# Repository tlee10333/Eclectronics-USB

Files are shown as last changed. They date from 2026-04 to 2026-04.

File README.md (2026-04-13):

# Eclectronics Spring 2026 Final Project - Wireless USB Communication Board 
## By: Allan Huang, Trinity Lee, Venkadesh Eswaranandam

This repository contains documentation for a wireless USB communication board. 
TBD

# Documentation
Below are links to documentation provided by the official manufacturers and were used as reference for this project in schematic design and layout. 

## Nordic Semiconductor nRF5340 
[General Documentation Website](https://docs.nordicsemi.com/category/nrf5340-category)

[Download link to Product Specification PDF/Datasheet v1.6](https://docs-be.nordicsemi.com/bundle/ps_nrf5340/page/nRF5340_PS_v1.6.pdf?_LANG=enus) 

## Nordic Semiconductor nRF7002 
[General Documentation Website](https://docs.nordicsemi.com/category/nrf7002-category)

[Download link to Product Specification PDF/Datasheet v1.2](https://docs-be.nordicsemi.com/bundle/ps_nrf7002/attach/nRF7002_PS_v1.2.pdf?_LANG=enus)

## TS3USB30E Mux

[General Documentation Website](https://www.ti.com/product/TS3USB30E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)

[Link to Product Specification PDF/Datasheet](https://www.ti.com/lit/ds/symlink/ts3usb30e.pdf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)

## TBD
[General Documentation Website]()

[Download link to Product Specification PDF/Datasheet]()

# References
Below are links that were used for references (cthis section can be deleted if we want to)

[nRF7002 DK datasheet](https://docs-be.nordicsemi.com/bundle/ug_nrf7002_dk/attach/nRF7002_DK_User_Guide_v1.0.0.pdf?_LANG=enus)

[nRF5340 DK datasheet](https://docs-be.nordicsemi.com/bundle/ug_nrf5340_dk/attach/nRF5340_DK_User_Guide_v2.0.2.pdf?_LANG=enus)

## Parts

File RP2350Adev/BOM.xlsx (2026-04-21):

Id | Designator | Footprint | Quantity | Designation | Supplier and ref
1 | R405,R102,R101,R404 | R_0402_1005Metric | 4 | 27Ω
2 | R702,R701,R703,R704 | C_0402_1005Metric | 4 | 10K
3 | C407,C402,C417,C409,C410,C412,C408,C415,C411,C406 | R_0402_1005Metric | 10 | 0.1µF
4 | C201,C202 | C_0603_1608Metric | 2 | 4.7µF
5 | U201 | Nordic_AQFN-94-1EP_7x7mm_P0.4mm | 1 | nRF5340-QKxx
6 | D402,D201 | LED_0805_2012Metric | 2 | LED
7 | R201 | R_0402_1005Metric | 1 | 2.2 Ω
8 | U401 | SOT-223-3_TabPin2 | 1 | LD1117S33TR_SOT223
9 | C302,C303 | C_0603_1608Metric | 2 | 100nF
10 | C212,C214,C204,C215,C210,C213,C216,C211,C217 | C_0402_1005Metric | 9 | 100nF
11 | C308 | C_0603_1608Metric | 1 | 0.22uF
12 | C208,C203,C206,C207,C209 | C_0402_1005Metric | 5 | 1.0µF
13 | R705,R706 | C_0402_1005Metric | 2 | 5.1K
14 | D401 | LED_0805_2012Metric | 1 | PWR
15 | A301 | XCVR_NN03-320 | 1 | NN03-320
16 | J204 | PinHeader_1x03_P2.54mm_Vertical | 1 | UART Pins
17 | R406 | R_0402_1005Metric | 1 | 33Ω
18 | R401,R402,R408 | R_0402_1005Metric | 3 | 5.1K
19 | R410,R409,R202,R403,R407 | R_0402_1005Metric | 5 | 1K
20 | C314,C301 | C_0603_1608Metric | 2 | 0.47uF
21 | C306 | C_0805_2012Metric | 1 | 2.2uF
22 | R305,R302,R301,R303,R304 | R_0402_1005Metric | 5 | 100k
23 | J201 | PinHeader_1x03_P2.54mm_Vertical | 1 | J-Link
24 | L301 | L_0603_1608Metric | 1 | 7.5nH
25 | TP101 | TestPoint_Pad_D1.0mm | 1 | TestPoint
26 | C401,C403 | R_0402_1005Metric | 2 | 10µF
27 | C304,C316,C305,C315 | C_0805_2012Metric | 4 | 4.7uF
28 | C405,C414,C404,C416,C413 | R_0402_1005Metric | 5 | 4.7µF
29 | C307 | C_0603_1608Metric | 1 | 22nF
30 | C313,C310,C312,C311 | C_0603_1608Metric | 4 | 1uF
31 | X301 | XTAL_ABM11W-32.0000MHZ-8-D1X-T3 | 1 | XTAL-40
32 | C317 | C_0603_1608Metric | 1 | 10nF
33 | S401 | SW_SPST_B3U-1000P | 1 | RST
34 | J402 | PinHeader_1x03_P2.54mm_Vertical | 1 | DEBUG
35 | J203 | PinHeader_1x09_P2.54mm_Vertical | 1 | QSPI Pins
36 | U701 | VSSOP-10_3x3mm_P0.5mm | 1 | TS3USB30EDGSR
37 | L202 | INDC1608X95N | 1 | 10µH
38 | J401 | PinHeader_1x03_P2.54mm_Vertical | 1 | UART
39 | X202 | XTAL_CM9V-T1A-32.768KHZ-9PF-20PPM-TA-QC | 1 | 32.768kHz
40 | C309,C318 | C_0603_1608Metric | 2 | 2.2uF
41 | U301 | SC-74A-5_1.55x2.9mm_P0.95mm | 1 | TCK106AF
42 | L201 | INDC1608X95N | 1 | 10uH
43 | U403 | RP2350A_QFN-60_EP_7.75x7.75_Pitch0.4mm | 1 | RP2350A
44 | J702 | USB_A_Stewart_SS-52100-001_Horizontal | 1 | USB_A_Female
45 | S402 | SW_SPST_B3U-1000P | 1 | BOOT
46 | C702,C701 | C_0402_1005Metric | 2 | 1uF
47 | SW701 | SW_DIP_SPSTx06_Piano_10.8x16.8mm_W7.62mm_P2.54mm | 1 | SW_DIP_x06
48 | L304 | L_1008_2520Metric | 1 | 3.3uH
49 | X401 | IQXO-791 | 1 | IQXO-791
50 | L302,L303 | L_0603_1608Metric | 2 | 2.7nH
51 | U302 | FIL_LFD182G45DCJD247 | 1 | LFD_Diplexer
52 | J202 | PinHeader_1x04_P2.54mm_Vertical | 1 | SPI Pins
53 | U303 | QFN-48-1EP_6x6mm_P0.4mm_EP4.6x4.6mm | 1 | nRF7002-QFAA
54 | M701 | RMG12_TEX | 1 | TS3USB3031RMGR
55 | C205 | C_0402_1005Metric | 1 | 2.2nF
56 | X201 | XTAL_ABM11W-32.0000MHZ-8-D1X-T3 | 1 | 32MHz
57 | U402 | WSON-8-1EP_6x5mm_P1.27mm_EP3.4x4.3mm | 1 | W25Q32JV
58 | J703 | USB4105-GF-A | 1 | USB4105-GF-A
59 | J701 | USB_A_0480370001 | 1 | USB_A_Male
60 | D403 | IN-S85TATRGB | 1 | IN-S85TATRGB
61 | L401 | AOTA-B201610S3R3-101-T | 1 | 3.3µH

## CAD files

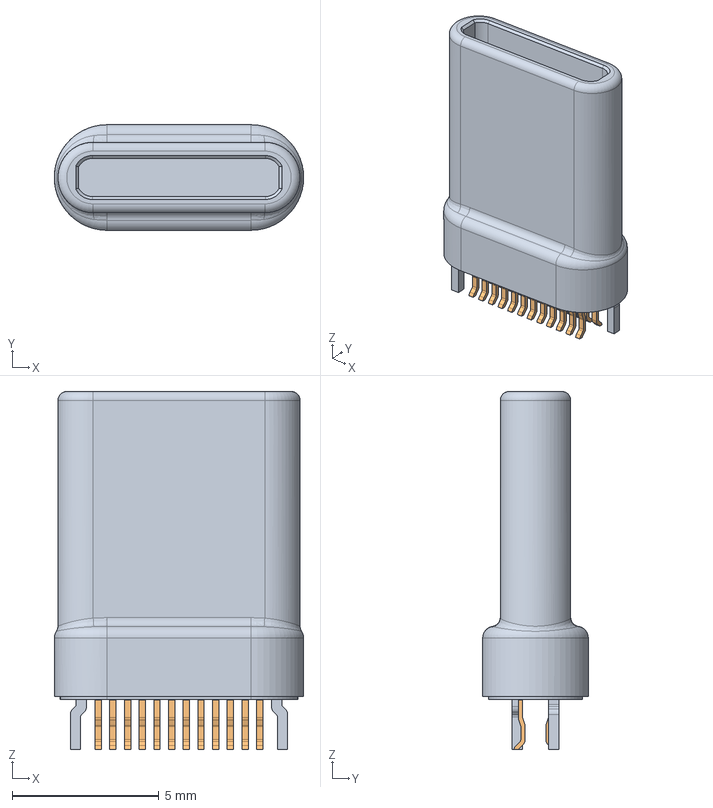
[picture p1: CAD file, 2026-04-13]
Eclectronics/3dshapes/plug-usbc-241smtv-4bs60_asm.stp
8.50 x 3.60 x 12.2 mm
PLUG-USBC-241SMTV-4BS60_1
PLUG-USBC-241SMTV-4BS60_2
PLUG-USBC-241SMTV-4BS60_3
PLUG-USBC-241SMTV-4BS60_4
PLUG-USBC-241SMTV-4BS60_5
PLUG-USBC-241SMTV-4BS60_6
PLUG-USBC-241SMTV-4BS60_7
PLUG-USBC-241SMTV-4BS60_8
PLUG-USBC-241SMTV-4BS60_9
PLUG-USBC-241SMTV-4BS60_10
PLUG-USBC-241SMTV-4BS60_11
PLUG-USBC-241SMTV-4BS60_12
PLUG-USBC-241SMTV-4BS60_13
PLUG-USBC-241SMTV-4BS60_14
PLUG-USBC-241SMTV-4BS60_15
PLUG-USBC-241SMTV-4BS60_16
PLUG-USBC-241SMTV-4BS60_17
PLUG-USBC-241SMTV-4BS60_18
PLUG-USBC-241SMTV-4BS60_19
PLUG-USBC-241SMTV-4BS60_20
PLUG-USBC-241SMTV-4BS60_21
PLUG-USBC-241SMTV-4BS60_22
PLUG-USBC-241SMTV-4BS60_23
PLUG-USBC-241SMTV-4BS60_24
PLUG-USBC-241SMTV-4BS60_25

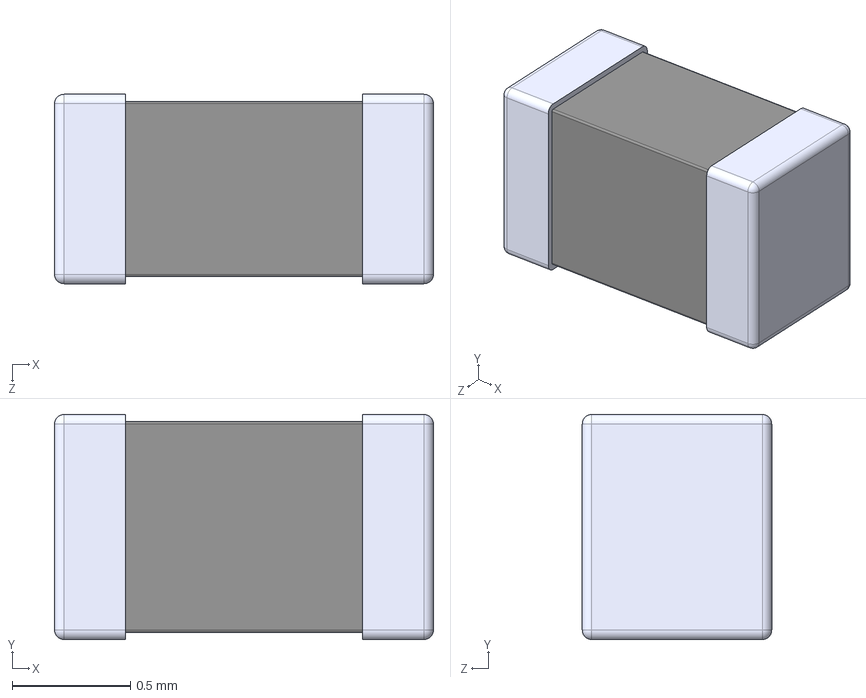
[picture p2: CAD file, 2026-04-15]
Eclectronics/3dshapes/MLZ1608M100WTD25.step
1.60 x 0.95 x 0.8 mm

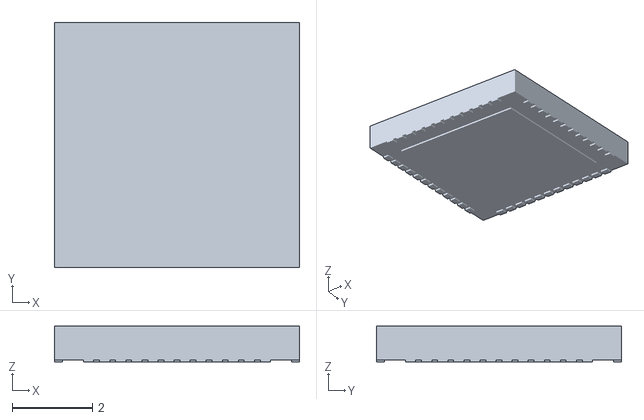
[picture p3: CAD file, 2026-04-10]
RP2350Adev/NRF7002_QFAA_R/QFN48_6X6_NOR.stl
6.10 x 6.10 x 0.892

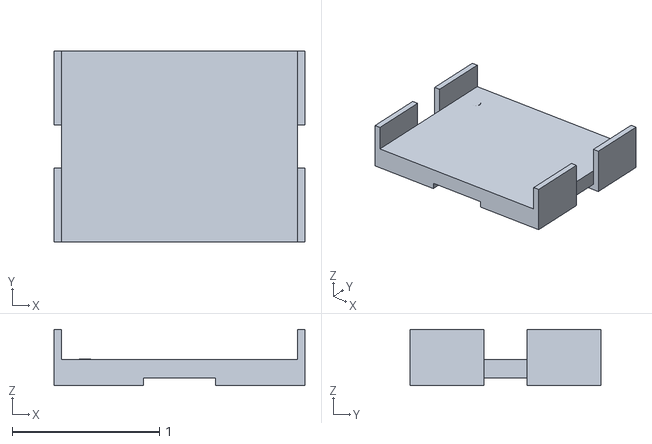
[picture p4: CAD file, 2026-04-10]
RP2350Adev/OSC/KiCADv6/SON_CX1612DB40000D0WLLCC_KAV.stl
1.70 x 1.30 x 0.381

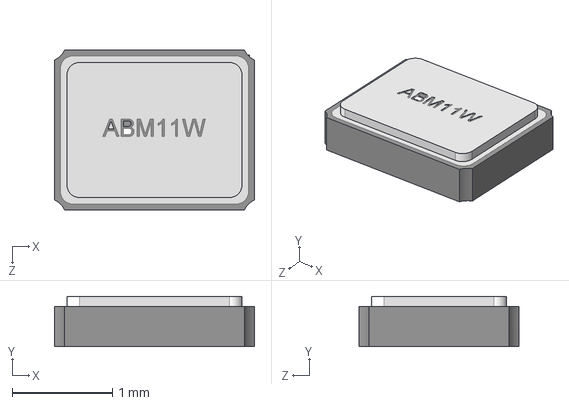
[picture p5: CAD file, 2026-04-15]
Eclectronics/3dshapes/ABM11W-32.0000MHZ-8-D1X-T3.step
2.00 x 0.5 x 1.60 mm

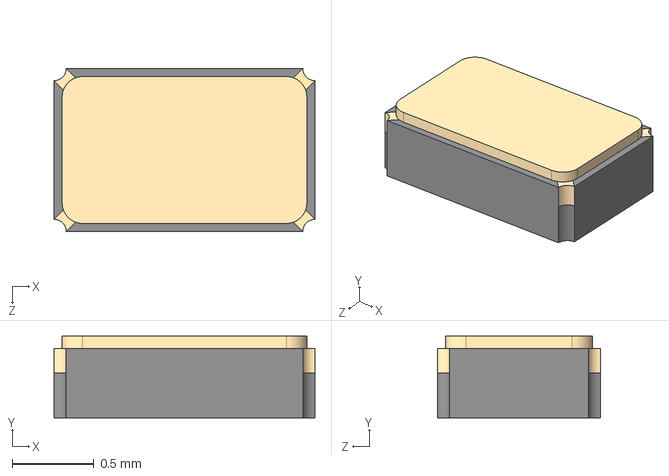
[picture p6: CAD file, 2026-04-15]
Eclectronics/3dshapes/CM9V-T1A-32.768KHZ-9PF-20PPM-TA-QC.step
1.60 x 0.5 x 1.00 mm

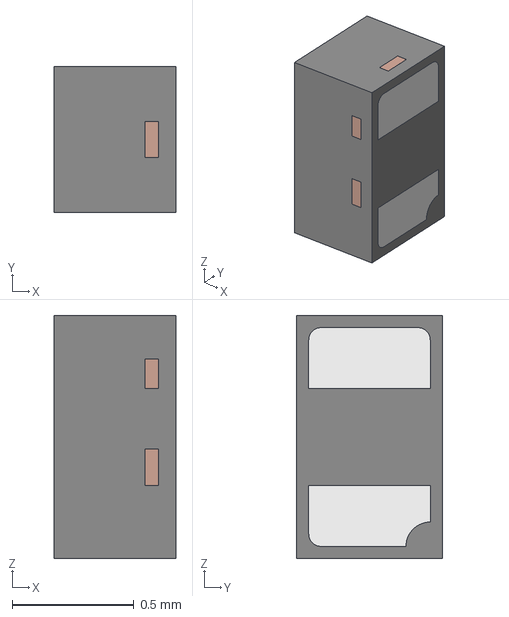
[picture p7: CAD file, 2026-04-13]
Eclectronics/3dshapes/DFN1006-2.stp
0.5 x 0.6 x 1.00 mm
LDF

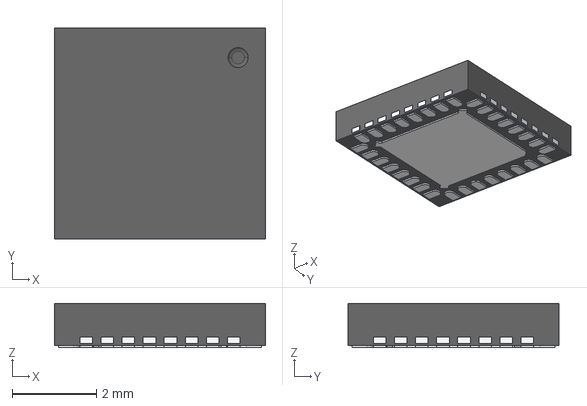
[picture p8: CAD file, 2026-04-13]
Eclectronics/3dshapes/QFN-32_5x5.stp
5.00 x 5.00 x 1.05 mm

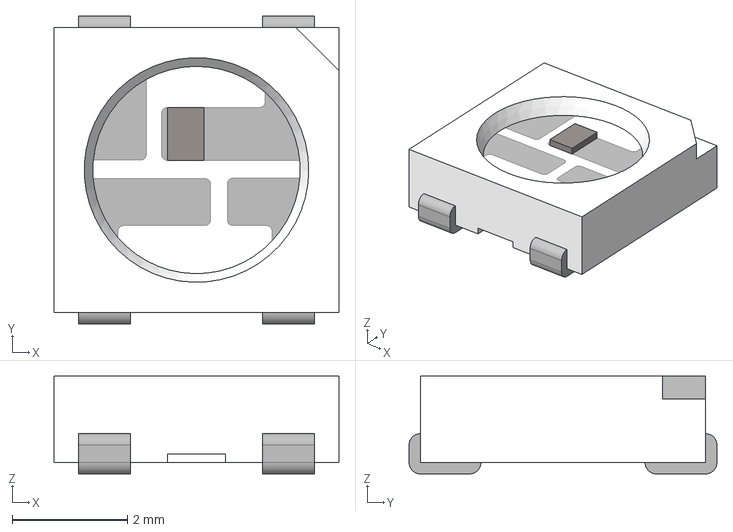
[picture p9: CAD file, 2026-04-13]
Eclectronics/3dshapes/WS2812_RGB_LED_updated.stp
4.95 x 5.35 x 1.70 mm

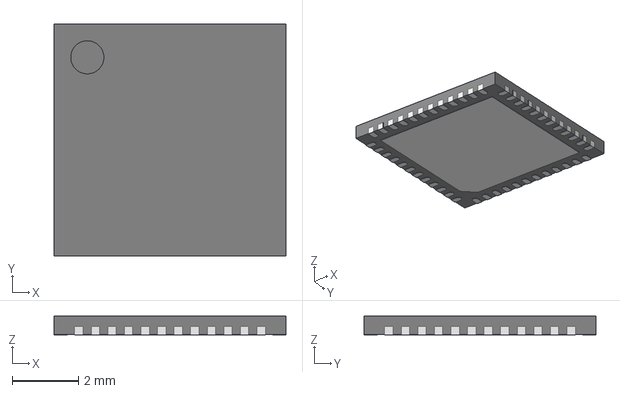
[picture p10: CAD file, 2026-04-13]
Eclectronics/3dshapes/UFQFPN48.stp
7.00 x 7.00 x 0.57 mm

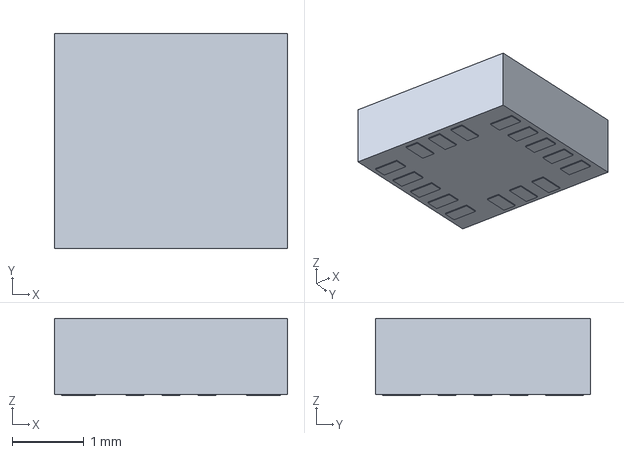
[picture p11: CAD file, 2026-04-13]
Eclectronics/3dshapes/Analog_Devices_Inc_-_ADXL362BCCZ.step
3.25 x 3.00 x 1.08 mm

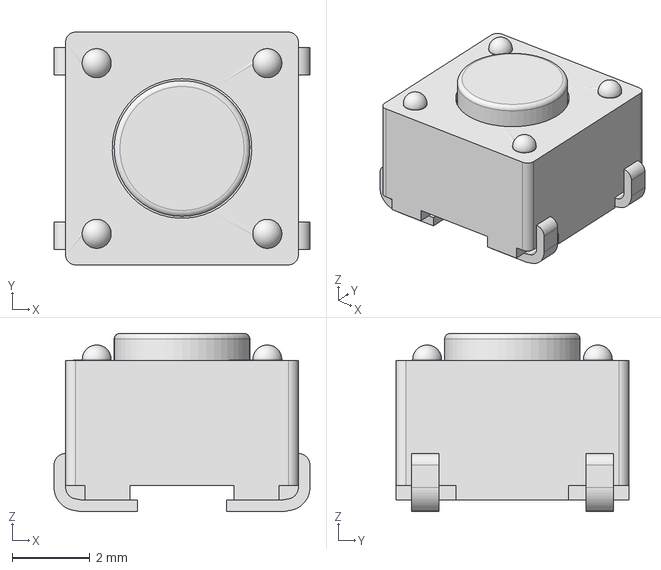
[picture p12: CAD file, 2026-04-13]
Eclectronics/3dshapes/TL3301NFxxxxJ.stp
6.60 x 6.00 x 4.60 mm

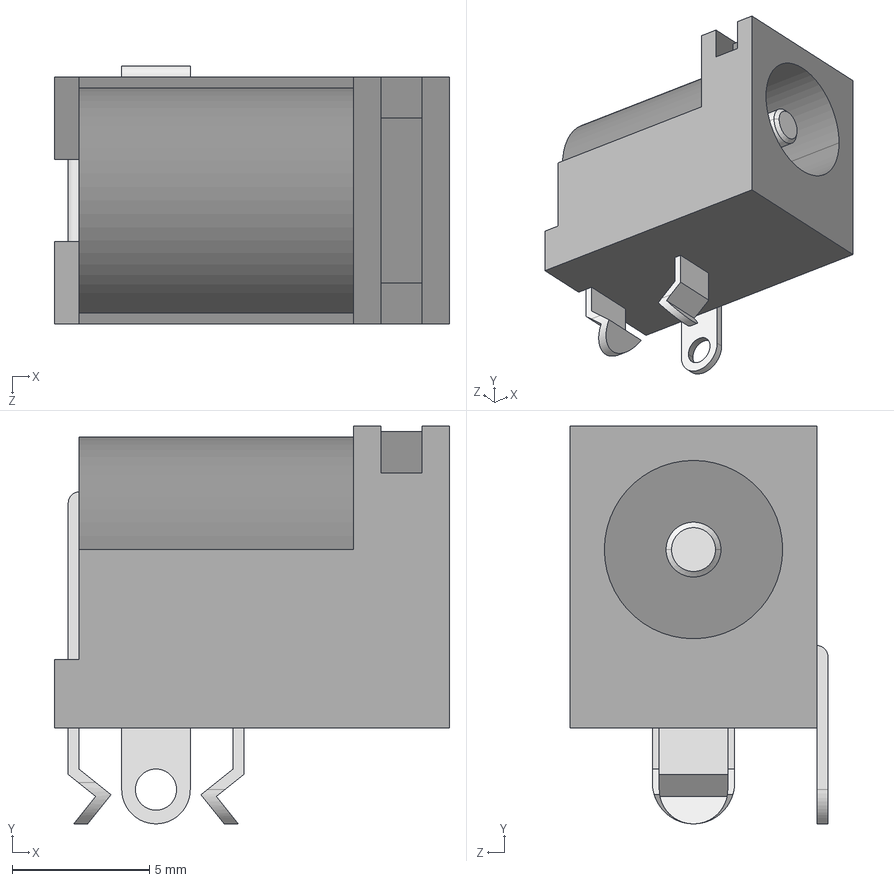
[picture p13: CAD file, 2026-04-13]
Eclectronics/3dshapes/CUI_DEVICES_PJ-202A.step
14.4 x 14.5 x 9.40 mm

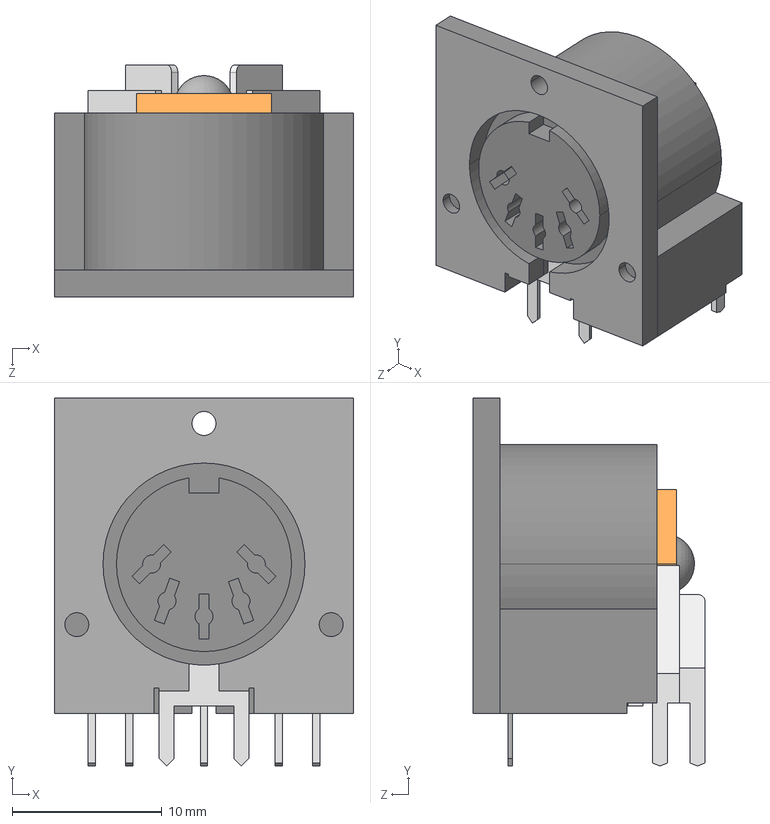
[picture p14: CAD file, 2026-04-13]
Eclectronics/3dshapes/CUI_SDS-50J.step
20.0 x 24.6 x 15.5 mm

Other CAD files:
Eclectronics/3dshapes/DFN8_3x3_0.65.step
Eclectronics/3dshapes/RP2350A-QFN60.step
Eclectronics/3dshapes/BarrelJack.STEP
Eclectronics/3dshapes/WSON8-6x5.STEP
Eclectronics/3dshapes/1725656.stp
Eclectronics/3dshapes/219-3M.STEP
Eclectronics/3dshapes/3382g-001-xxx.stp
Eclectronics/3dshapes/5442565.stp
Eclectronics/3dshapes/ABM10-27.000MHZ-E20-T.step
Eclectronics/3dshapes/ABM10.STP
Eclectronics/3dshapes/ABS06-107.STP
Eclectronics/3dshapes/AOTA-B201610S3R3-101-T.stp
Eclectronics/3dshapes/B4B-XH-A.step
Eclectronics/3dshapes/CSTNE.step
Eclectronics/3dshapes/DFN-8-3x3-0_5.STEP
Eclectronics/3dshapes/EEEFTH101XAL.step
Eclectronics/3dshapes/IN-S85TATRGB.stp
Eclectronics/3dshapes/KXT321LHS.stp
Eclectronics/3dshapes/PA5003.182NLT.step
Eclectronics/3dshapes/RNR0011A.stp
Eclectronics/3dshapes/RP2040_QFN_PACKAGE.STEP
Eclectronics/3dshapes/RTE0020A.stp
Eclectronics/3dshapes/S4B-PH-SM4-TB.stp
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

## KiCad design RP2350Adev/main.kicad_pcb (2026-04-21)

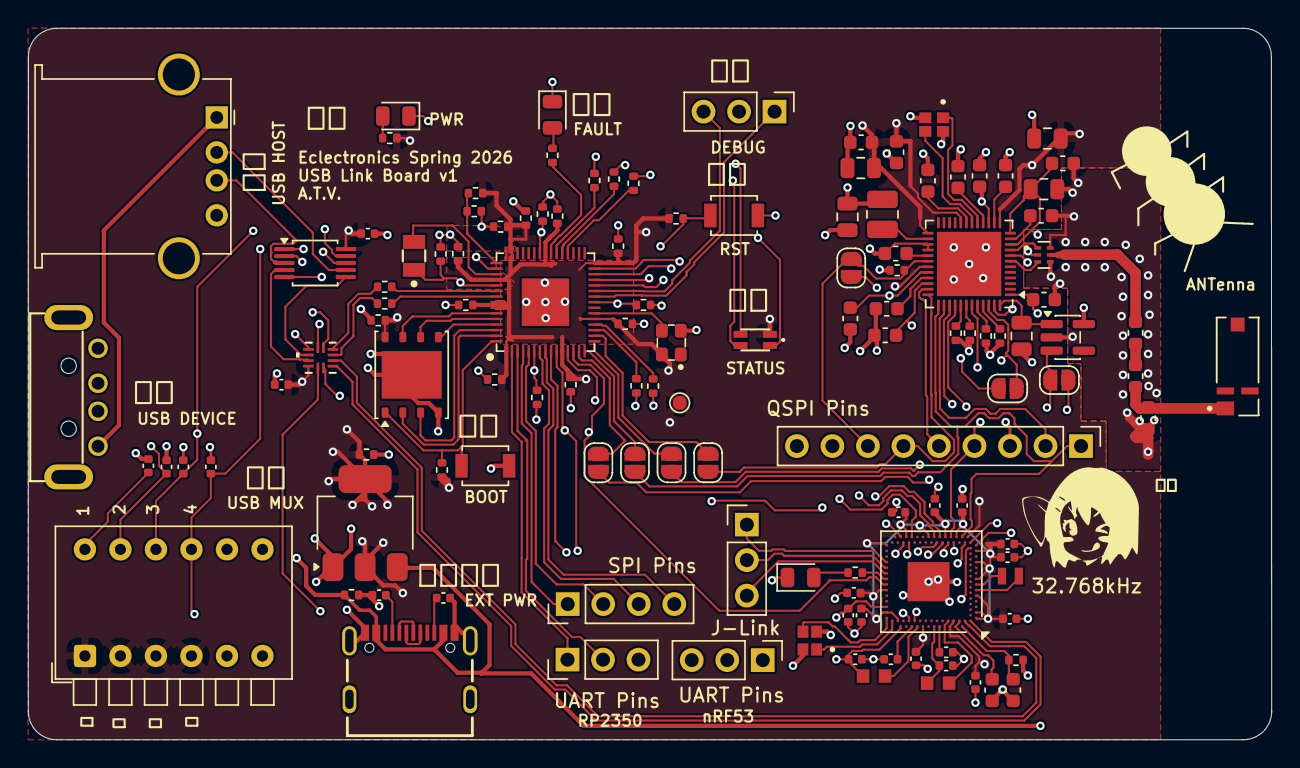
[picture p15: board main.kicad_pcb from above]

Board: 4 copper layers, 88.9 x 50.9 mm, 124 parts (0 on the bottom side), 111 nets.

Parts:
A301: NN03-320; XCVR_NN03-320
C201, C202: 4.7µF; C_0603_1608Metric
C203, C206, C207, C208, C209: 1.0µF; C_0402_1005Metric
C204, C210, C211, C212, C213, C214, C215, C216, C217: 100nF; C_0402_1005Metric
C205: 2.2nF; C_0402_1005Metric
C301, C314: 0.47uF; C_0603_1608Metric
C302, C303: 100nF; C_0603_1608Metric
C304, C305, C315, C316: 4.7uF; C_0805_2012Metric
C306: 2.2uF; C_0805_2012Metric
C307: 22nF; C_0603_1608Metric
C308: 0.22uF; C_0603_1608Metric
C309, C318: 2.2uF; C_0603_1608Metric
C310, C311, C312, C313: 1uF; C_0603_1608Metric
C317: 10nF; C_0603_1608Metric
C401, C403: 10µF; R_0402_1005Metric
C402, C406, C407, C408, C409, C410, C411, C412, C415, C417: 0.1µF; R_0402_1005Metric
C404, C405, C413, C414, C416: 4.7µF; R_0402_1005Metric
C701, C702: 1uF; C_0402_1005Metric
D201, D402: LED; LED_0805_2012Metric
D401: PWR; LED_0805_2012Metric
D403: IN-S85TATRGB
J201: J-Link; PinHeader_1x03_P2.54mm_Vertical
J202: SPI Pins; PinHeader_1x04_P2.54mm_Vertical
J203: QSPI Pins; PinHeader_1x09_P2.54mm_Vertical
J204: UART Pins; PinHeader_1x03_P2.54mm_Vertical
J401: UART; PinHeader_1x03_P2.54mm_Vertical
J402: DEBUG; PinHeader_1x03_P2.54mm_Vertical
J701: USB_A_Male; USB_A_0480370001
J702: USB_A_Female; USB_A_Stewart_SS-52100-001_Horizontal
J703: USB4105-GF-A
JP101, JP102, JP103, JP104, JP105, JP106, JP107: SolderJumper_2_Open; SolderJumper-2_P1.3mm_Open_RoundedPad1.0x1.5mm
L201: 10uH; INDC1608X95N
L202: 10µH; INDC1608X95N
L301: 7.5nH; L_0603_1608Metric
L302, L303: 2.7nH; L_0603_1608Metric
L304: 3.3uH; L_1008_2520Metric
L401: 3.3µH; AOTA-B201610S3R3-101-T
M701: TS3USB3031RMGR; RMG12_TEX
R101, R102, R404, R405: 27Ω; R_0402_1005Metric
R201: 2.2 Ω; R_0402_1005Metric
R202, R403, R407, R409, R410: 1K; R_0402_1005Metric
R301, R302, R303, R304, R305: 100k; R_0402_1005Metric
R401, R402, R408: 5.1K; R_0402_1005Metric
R406: 33Ω; R_0402_1005Metric
R701, R702, R703, R704: 10K; C_0402_1005Metric
R705, R706: 5.1K; C_0402_1005Metric
S401: RST; SW_SPST_B3U-1000P
S402: BOOT; SW_SPST_B3U-1000P
SW701: SW_DIP_x06; SW_DIP_SPSTx06_Piano_10.8x16.8mm_W7.62mm_P2.54mm
TP101: TestPoint; TestPoint_Pad_D1.0mm
U201: nRF5340-QKxx; Nordic_AQFN-94-1EP_7x7mm_P0.4mm
U301: TCK106AF; SC-74A-5_1.55x2.9mm_P0.95mm
U302: LFD_Diplexer; FIL_LFD182G45DCJD247
U303: nRF7002-QFAA; QFN-48-1EP_6x6mm_P0.4mm_EP4.6x4.6mm
U401: LD1117S33TR_SOT223; SOT-223-3_TabPin2
U402: W25Q32JV; WSON-8-1EP_6x5mm_P1.27mm_EP3.4x4.3mm
U403: RP2350A; RP2350A_QFN-60_EP_7.75x7.75_Pitch0.4mm
U701: TS3USB30EDGSR; VSSOP-10_3x3mm_P0.5mm
X201: 32MHz; XTAL_ABM11W-32.0000MHZ-8-D1X-T3
X202: 32.768kHz; XTAL_CM9V-T1A-32.768KHZ-9PF-20PPM-TA-QC
X301: XTAL-40; XTAL_ABM11W-32.0000MHZ-8-D1X-T3
X401: IQXO-791

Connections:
+1V1: C405.2, C415.2, C416.2, C417.2, L401.1, U403.6 (DVDD), U403.23 (DVDD), U403.39 (DVDD), U403.50 (VREG_FB)
+3V3: C208.2, C209.2, C210.2, C211.2, C212.2, C213.2, C214.2, C215.2, C216.2, C217.2, C305.1, C311.1, C315.1, C318.1, C402.2, C403.1, C404.2, C406.2, C407.2, C408.2, C409.2, C410.2, C411.2, C412.2, C413.2, C701.2, C702.2, D403.3, M701.12 (VCC), R401.1, R402.1, R403.1, R406.2, SW701.1, SW701.2, SW701.3, SW701.4, TP101.1, U201.A19 (VDD), U201.AC1 (VDD), U201.AG1 (VDD), U201.AJ31 (VDD), U201.AL3 (VDD), U201.AL7 (VDD), U201.AL11 (VDD), U201.AL17 (VDD), U201.AL25 (VDD), U201.B8 (VDD), U201.B28 (VDD), U201.C1 (VDD), U201.E1 (VDDH), U201.E31 (VDD), U201.L1 (VDD), U201.N31 (VDD), U201.U1 (VDD), U301.5 (VIN), U303.13 (VBAT), U303.20 (AFEVBAT), U303.25 (BUCKVBAT), U303.31 (BUCKVBATS), U401.2 (VO), U402.8 (VDD), U403.1 (IOVDD), U403.11 (IOVDD), U403.20 (IOVDD), U403.30 (IOVDD), U403.38 (IOVDD), U403.44 (ADC_AVDD), U403.45 (IOVDD), U403.49 (VREG_VIN), U403.53 (USB_OTP_VDD), U403.54 (QSPI_IOVDD), U701.10 (VCC), X401.4 (VS)
+5V: C401.2, J701.1 (VBUS), J702.1 (VBUS), J703.A4B9 (VBUS), J703.B4A9 (VBUS), R201.1, U401.3 (VI)
/RP2350Adev/BOOT: R402.2, S402.2, U402.1 (~CS), U403.60 (~QSPI_CS)
/RP2350Adev/BUCK_EN: JP101.1 (A), U403.28 (GPIO17)
/RP2350Adev/D1+: M701.5 (USB2+), R405.1
/RP2350Adev/D1-: M701.6 (USB2-), R404.1
/RP2350Adev/D2+: R101.2, U403.18 (GPIO14)
/RP2350Adev/D2-: R102.2, U403.19 (GPIO15)
/RP2350Adev/GPIO22: R407.1, U403.34 (GPIO22)
/RP2350Adev/GPIO23: R408.1, U403.35 (GPIO23)
/RP2350Adev/GPIO24: R409.1, U403.36 (GPIO24)
/RP2350Adev/GPIO25: R410.1, U403.37 (GPIO25)
/RP2350Adev/HOST_IRQ: JP102.1 (A), U403.27 (GPIO16)
/RP2350Adev/IOVDD_EN: JP107.2 (B), U403.29 (GPIO18)
/RP2350Adev/MUX1_S0: M701.1 (SEL0), R701.1, SW701.12, U201.R31 (P1.10), U403.13 (GPIO9)
/RP2350Adev/MUX1_S1: M701.2 (SEL1), R702.1, SW701.11, U201.AK26 (P1.09), U403.12 (GPIO8)
/RP2350Adev/MUX2_OE: R703.1, SW701.10, U201.AL23 (P1.08), U403.10 (GPIO7), U701.9 (~OE)
/RP2350Adev/MUX2_S: R704.1, SW701.9, U201.AK24 (P1.07), U403.9 (GPIO6), U701.1 (S)
/RP2350Adev/RUN: R401.2, S401.2, U403.26 (RUN)
/RP2350Adev/SPI_CLK: J202.1, U201.AH2 (SCK/TRACEDATA3/P0.08), U403.4 (GPIO2)
/RP2350Adev/SPI_CLK2: JP106.1 (A), U403.14 (GPIO10)
/RP2350Adev/SPI_MISO: J202.3, U201.AK2 (MISO/TRACEDATA1/P0.10), U403.7 (GPIO4)
/RP2350Adev/SPI_MISO2: JP104.1 (A), U403.16 (GPIO12)
/RP2350Adev/SPI_MOSI: J202.2, U201.AJ1 (MOSI/TRACEDATA2/P0.09), U403.5 (GPIO3)
/RP2350Adev/SPI_MOSI2: JP103.1 (A), U403.15 (GPIO11)
/RP2350Adev/SPI_SS: J202.4, U201.AK4 (CSN/TRACEDATA0/P0.11), U403.8 (GPIO5)
/RP2350Adev/SPI_SS2: JP105.1 (A), U403.17 (GPIO13)
/RP2350Adev/SWCLK: J402.1, U403.24 (SWCLK)
/RP2350Adev/SWDIO: J402.3, U403.25 (SWDIO)
/USB_Mux_Periph/D1+: M701.3 (USB1+), U201.B2 (D+)
/USB_Mux_Periph/D1-: M701.4 (USB1-), U201.B4 (D-)
/USB_Mux_Periph/D3+: M701.7 (MHL+), R101.1
/USB_Mux_Periph/D3-: M701.8 (MHL-), R102.1
/nRF5340/BUCKEN: J203.7, JP101.2 (B), R301.1, U201.AL13 (P0.19), U303.30 (BUCKEN)
/nRF5340/COEX: J203.8, U303.43 (COEX_GRANT)
/nRF5340/HOST_IRQ: J203.9, JP102.2 (B), U201.AL15 (P0.21), U303.46 (HOST_IRQ)
/nRF5340/IOVDD_EN: JP107.1 (A), U201.AL27 (P0.24), U301.3 (CTRL)
/nRF5340/QSPI0: J203.1, JP103.2 (B), U201.AL5 (IO0/P0.13), U303.37 (QSPI_DATA0)
/nRF5340/QSPI1: J203.2, JP104.2 (B), U201.AK8 (IO1/P0.14), U303.38 (QSPI_DATA1)
/nRF5340/QSPI2: J203.3, U201.AK10 (IO2/P0.15), U303.39 (QSPI_DATA2)
/nRF5340/QSPI3: J203.4, U201.AL9 (IO3/P0.16), U303.40 (QSPI_DATA3)
/nRF5340/QSPI_CLK: J203.5, JP106.2 (B), U201.AK12 (SCK/P0.17), U303.35 (QSPI_CLK)
/nRF5340/QSPI_SS: J203.6, JP105.2 (B), U201.AK14 (CSN/P0.18), U303.36 (QSPI_SS)
/nRF5340/RX: J204.2, U201.B24 (P0.30)
/nRF5340/TX: J204.1, U201.B22 (P0.31)
/nRF7002/PWR_IOVDD: C303.1, C312.1, U303.1 (OTPVDD), U303.34 (PWRIOVDD)
/nRF7002/VDD_BUCK: C308.1, C314.1, C316.1, L304.2, U303.15 (RFBUCKVDD), U303.32 (PWRBUCKVDD)
GND: C201.2, C202.2, C203.2, C204.2, C205.2, C206.2, C207.2, C208.1, C209.1, C210.1, C211.1, C212.1, C213.1, C214.1, C215.1, C216.1, C217.1, C301.2, C302.2, C303.2, C304.2, C305.2, C306.2, C307.2, C308.2, C309.2, C310.2, C311.2, C312.2, C313.2, C314.2, C315.2, C316.2, C317.2, C318.2, C401.1, C402.1, C403.2, C404.1, C405.1, C406.1, C407.1, C408.1, C409.1, C410.1, C411.1, C412.1, C413.1, C414.1, C415.1, C416.1, C417.1, C701.1, C702.1, D201.1 (K), D401.1 (K), D402.1 (K), J204.3, J401.3, J402.2, J701.4 (GND), J701.5 (Shield), J702.4 (GND), J702.5 (Shield), J703.A1B12 (GND), J703.B1A12 (GND), J703.S1 (SHELL), J703.S2 (SHELL), J703.S3 (SHELL), J703.S4 (SHELL), L301.2, M701.9 (GND), R301.2, R302.2, R303.2, R304.2, R305.2, R701.2, R702.2, R703.2, R704.2, R705.2, R706.2, S401.1, S402.1, U201.EP (VSS), U301.2 (GND), U302.2 (GND), U302.5 (GND), U302.7 (GND), U303.27 (BUCKVSS), U303.28 (BUCKVSS), U303.47 (VSS), U303.49 (VSS), U401.1 (GND), U402.4 (GND), U402.9 (EP), U403.47 (VREG_PGND), U403.61 (GND), U701.5 (GND), X201.2 (G), X201.4 (G), X301.2 (G), X301.4 (G), X401.2 (GND)
unnamed: A301.1 (A), L301.1, L302.1
unnamed: D201.2 (A), R202.2
unnamed: D401.2 (A), R403.2
unnamed: D402.2 (A), R410.2
unnamed: D403.1, R407.2
unnamed: D403.2, R408.2
unnamed: D403.4, R409.2
unnamed: J201.1, U201.AC31 (~RESET)
unnamed: J201.2, U201.AA31 (SWDIO)
unnamed: J201.3, U201.W31 (SWDCLK)
unnamed: J401.1, U403.2 (GPIO0)
unnamed: J401.2, U403.3 (GPIO1)
unnamed: J701.3 (D+), U701.2 (D1+)
unnamed: J701.2 (D-), U701.8 (D1-)
unnamed: J702.3 (D+), U701.3 (D2+)
unnamed: J702.2 (D-), U701.7 (D2-)
unnamed: J703.A5 (CC1), R706.1
unnamed: J703.B5 (CC2), R705.1
unnamed: L302.2, L303.1
unnamed: M701.11 (D+), U701.4 (D+)
unnamed: M701.10 (D-), U701.6 (D-)
unnamed: L201.1, U201.A21 (DCC)
unnamed: L202.1, U201.B10 (DCCD)
unnamed: C207.1, U201.A13 (DECA)
unnamed: C206.1, L202.2, U201.A15 (DECD)
unnamed: C204.1, U201.A23 (DECN)
unnamed: C203.1, C205.1, L201.2, U201.A27 (DECR), U201.G31 (DECRF)
unnamed: C202.1, U201.B6 (DECUSB)
unnamed: R202.1, U201.U31 (P0.29)
unnamed: C201.1, R201.2, U201.A5 (VBUS)
unnamed: U201.C31 (XC1), X201.3
unnamed: U201.B30 (XC2), X201.1
unnamed: U201.N1 (XL1/P0.00), X202.1
unnamed: U201.R1 (XL2/P0.01), X202.2
unnamed: C306.1, U301.1 (VOUT), U303.48 (IOVDD)
unnamed: U302.1 (2.4G), U303.9 (TXRF0)
unnamed: U302.3 (5G), U303.7 (TXRF1)
unnamed: L303.2, U302.6 (COM)
unnamed: C310.1, U303.19 (AFELDO)
unnamed: L304.1, U303.26 (BUCKOUT)
unnamed: C317.1, U303.29 (BUCKVMID)
unnamed: R303.1, U303.42 (COEX_REQ)
unnamed: R302.1, U303.41 (COEX_STATUS0)
unnamed: C313.1, U303.33 (DIGVDD)
unnamed: C302.1, C304.1, U303.8 (PAVDD1), U303.10 (PAVDD0), U303.12 (PALDO)
unnamed: C307.1, U303.14 (RFVDD)
unnamed: R304.1, U303.44 (SW_CTRL0)
unnamed: R305.1, U303.45 (SW_CTRL1)
unnamed: C301.1, U303.11 (SXLDO)
unnamed: C309.1, U303.16 (XOLDO)
unnamed: U303.18 (XON), X301.3
unnamed: U303.17 (XOP), X301.1
unnamed: U402.5 (DI/IO0), U403.57 (QSPI_SD0)
unnamed: U402.2 (DO/IO1), U403.59 (QSPI_SD1)
unnamed: U402.6 (SCK), U403.56 (QSPI_SCLK)
unnamed: U402.7 (~HOLD/IO3), U403.55 (QSPI_SD3)
unnamed: U402.3 (~WP/IO2), U403.58 (QSPI_SD2)
unnamed: R405.2, U403.52 (USB_D+)
unnamed: R404.2, U403.51 (USB_D-)
unnamed: C414.2, R406.1, U403.46 (VREG_AVDD)
unnamed: L401.2, U403.48 (VREG_LX)
unnamed: U403.21 (XIN), X401.3 (OUT)

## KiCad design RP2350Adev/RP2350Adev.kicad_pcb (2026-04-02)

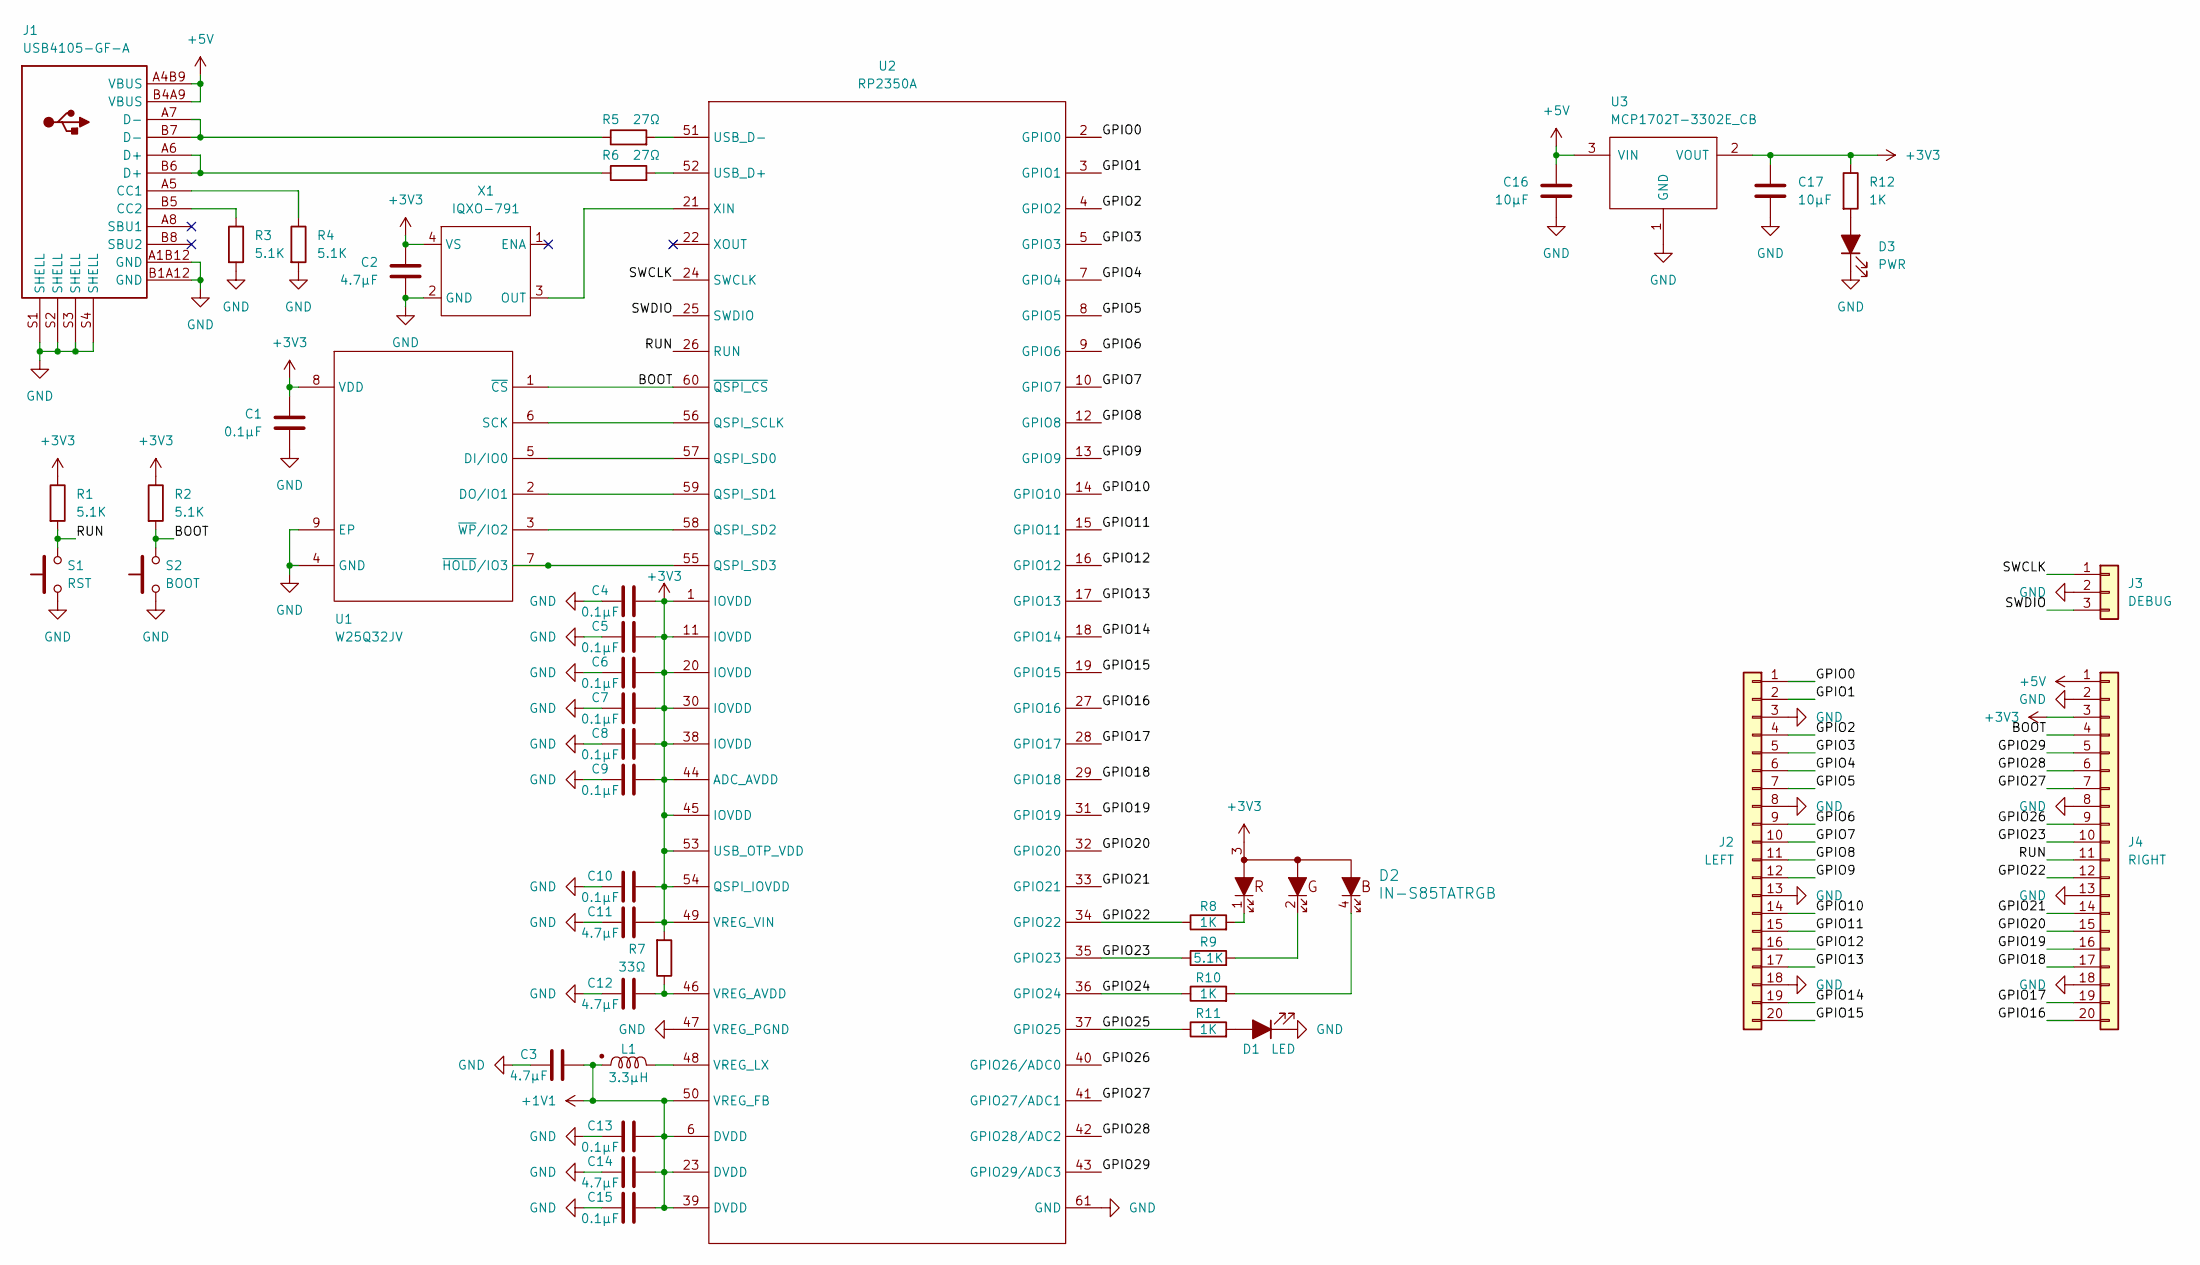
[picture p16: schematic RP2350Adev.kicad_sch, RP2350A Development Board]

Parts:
C1, C4, C5, C6, C7, C8, C9, C10, C13, C15: 0.1µF; R_0402_1005Metric
C2, C3, C11, C12, C14: 4.7µF; R_0402_1005Metric
C16, C17: 10µF; R_0402_1005Metric
D1: LED; LED_0805_2012Metric
D2: IN-S85TATRGB
D3: PWR; LED_0805_2012Metric
J1: USB4105-GF-A
J2: LEFT; PinHeader_1x20_P2.54mm_Vertical
J3: DEBUG; PinHeader_1x03_P1.00mm_Vertical
J4: RIGHT; PinHeader_1x20_P2.54mm_Vertical
L1: 3.3µH; AOTA-B201610S3R3-101-T
R1, R2, R3, R4, R9: 5.1K; R_0402_1005Metric
R5, R6: 27Ω; R_0402_1005Metric
R7: 33Ω; R_0402_1005Metric
R8, R10, R11, R12: 1K; R_0402_1005Metric
S1: RST; SW_SPST_B3U-1000P
S2: BOOT; SW_SPST_B3U-1000P
U1: W25Q32JV; WSON-8-1EP_6x5mm_P1.27mm_EP3.4x4.3mm
U2: RP2350A; RP2350A_QFN-60_EP_7.75x7.75_Pitch0.4mm
U3: MCP1702T-3302E_CB; SOT95P255X145-3N
X1: IQXO-791

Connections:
+1V1: C3.2, C13.2, C14.2, C15.2, L1.1, U2.6 (DVDD), U2.23 (DVDD), U2.39 (DVDD), U2.50 (VREG_FB)
+3V3: C1.2, C2.2, C4.2, C5.2, C6.2, C7.2, C8.2, C9.2, C10.2, C11.2, C17.1, D2.3, J4.3, R1.1, R2.1, R7.2, R12.1, U1.8 (VDD), U2.1 (IOVDD), U2.11 (IOVDD), U2.20 (IOVDD), U2.30 (IOVDD), U2.38 (IOVDD), U2.44 (ADC_AVDD), U2.45 (IOVDD), U2.49 (VREG_VIN), U2.53 (USB_OTP_VDD), U2.54 (QSPI_IOVDD), U3.2 (VOUT), X1.4 (VS)
+5V: C16.2, J1.A4B9 (VBUS), J1.B4A9 (VBUS), J4.1, U3.3 (VIN)
/BOOT: J4.4, R2.2, S2.2, U1.1 (~CS), U2.60 (~QSPI_CS)
/GPIO0: J2.1, U2.2 (GPIO0)
/GPIO1: J2.2, U2.3 (GPIO1)
/GPIO2: J2.4, U2.4 (GPIO2)
/GPIO3: J2.5, U2.5 (GPIO3)
/GPIO4: J2.6, U2.7 (GPIO4)
/GPIO5: J2.7, U2.8 (GPIO5)
/GPIO6: J2.9, U2.9 (GPIO6)
/GPIO7: J2.10, U2.10 (GPIO7)
/GPIO8: J2.11, U2.12 (GPIO8)
/GPIO9: J2.12, U2.13 (GPIO9)
/GPIO10: J2.14, U2.14 (GPIO10)
/GPIO11: J2.15, U2.15 (GPIO11)
/GPIO12: J2.16, U2.16 (GPIO12)
/GPIO13: J2.17, U2.17 (GPIO13)
/GPIO14: J2.19, U2.18 (GPIO14)
/GPIO15: J2.20, U2.19 (GPIO15)
/GPIO16: J4.20, U2.27 (GPIO16)
/GPIO17: J4.19, U2.28 (GPIO17)
/GPIO18: J4.17, U2.29 (GPIO18)
/GPIO19: J4.16, U2.31 (GPIO19)
/GPIO20: J4.15, U2.32 (GPIO20)
/GPIO21: J4.14, U2.33 (GPIO21)
/GPIO22: J4.12, R8.1, U2.34 (GPIO22)
/GPIO23: J4.10, R9.1, U2.35 (GPIO23)
/GPIO24: R10.1, U2.36 (GPIO24)
/GPIO25: R11.1, U2.37 (GPIO25)
/GPIO26: J4.9, U2.40 (GPIO26/ADC0)
/GPIO27: J4.7, U2.41 (GPIO27/ADC1)
/GPIO28: J4.6, U2.42 (GPIO28/ADC2)
/GPIO29: J4.5, U2.43 (GPIO29/ADC3)
/RUN: J4.11, R1.2, S1.2, U2.26 (RUN)
/SWCLK: J3.1, U2.24 (SWCLK)
/SWDIO: J3.3, U2.25 (SWDIO)
GND: C1.1, C2.1, C3.1, C4.1, C5.1, C6.1, C7.1, C8.1, C9.1, C10.1, C11.1, C12.1, C13.1, C14.1, C15.1, C16.1, C17.2, D1.1 (K), D3.1 (K), J1.A1B12 (GND), J1.B1A12 (GND), J1.S1 (SHELL), J1.S2 (SHELL), J1.S3 (SHELL), J1.S4 (SHELL), J2.3, J2.8, J2.13, J2.18, J3.2, J4.2, J4.8, J4.13, J4.18, R3.2, R4.2, S1.1, S2.1, U1.4 (GND), U1.9 (EP), U2.47 (VREG_PGND), U2.61 (GND), U3.1 (GND), X1.2 (GND)
unnamed: D1.2 (A), R11.2
unnamed: D2.1, R8.2
unnamed: D2.2, R9.2
unnamed: D2.4, R10.2
unnamed: D3.2 (A), R12.2
unnamed: J1.A5 (CC1), R4.1
unnamed: J1.B5 (CC2), R3.1
unnamed: J1.A6 (D+), J1.B6 (D+), R6.1
unnamed: J1.A7 (D-), J1.B7 (D-), R5.1
unnamed: U1.5 (DI/IO0), U2.57 (QSPI_SD0)
unnamed: U1.2 (DO/IO1), U2.59 (QSPI_SD1)
unnamed: U1.6 (SCK), U2.56 (QSPI_SCLK)
unnamed: U1.7 (~HOLD/IO3), U2.55 (QSPI_SD3)
unnamed: U1.3 (~WP/IO2), U2.58 (QSPI_SD2)
unnamed: R6.2, U2.52 (USB_D+)
unnamed: R5.2, U2.51 (USB_D-)
unnamed: C12.2, R7.1, U2.46 (VREG_AVDD)
unnamed: L1.2, U2.48 (VREG_LX)
unnamed: U2.21 (XIN), X1.3 (OUT)

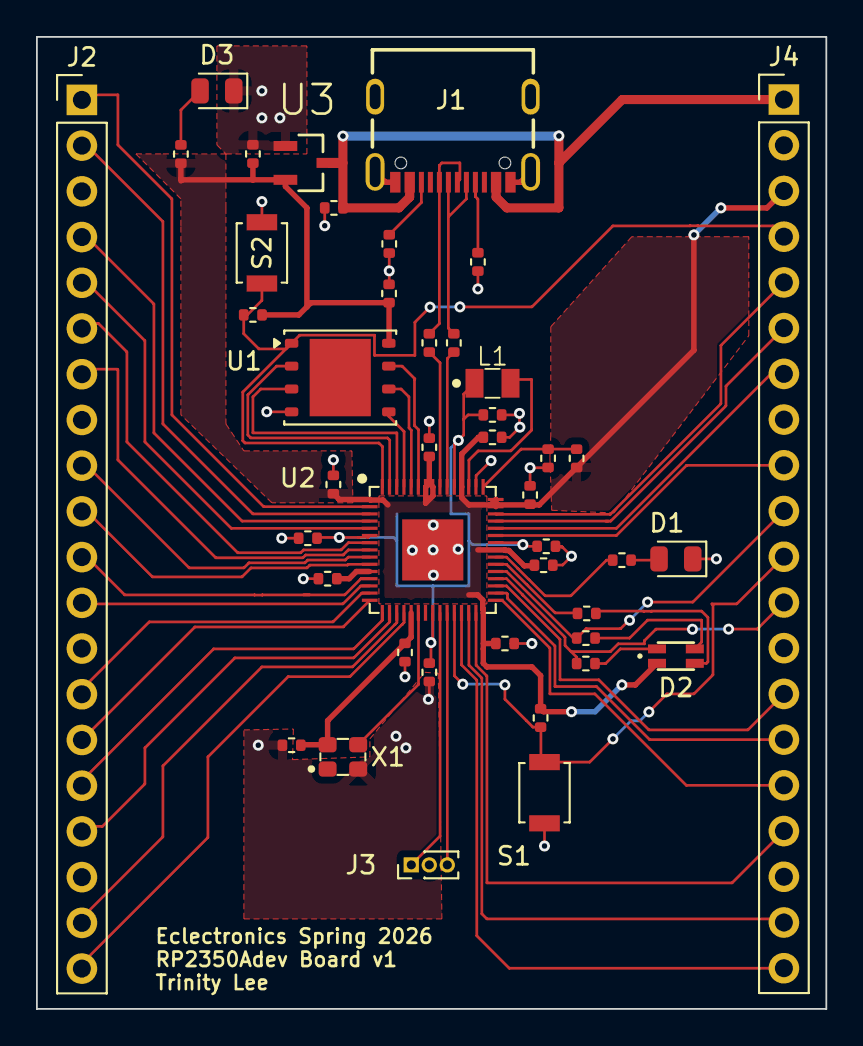
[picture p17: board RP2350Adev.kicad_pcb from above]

Board: 2 copper layers, 43.9 x 54.0 mm, 43 parts (0 on the bottom side), 57 nets.

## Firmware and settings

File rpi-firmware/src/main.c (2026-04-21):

#include <zephyr/kernel.h>
#include <zephyr/logging/log.h>
#include <zephyr/device.h>
#include <zephyr/devicetree.h>
#include <zephyr/drivers/gpio.h>
#include <zephyr/drivers/uart.h>
#include <errno.h>

#include <zephyr/net/dhcpv4_server.h>
#include <zephyr/net/net_if.h>
#include <zephyr/net/net_ip.h>
#include <zephyr/net/wifi_mgmt.h>

LOG_MODULE_REGISTER(app, LOG_LEVEL_INF);


static struct net_if *wifi_sap_iface(void)
{
	return net_if_get_wifi_sap();
}

static int configure_dhcpv4_server(struct net_if *iface, const char *addr_str)
{
	struct net_in_addr pool_base;
	struct net_in_addr addr;
	int ret;

	ret = net_addr_pton(NET_AF_INET, addr_str, &addr);
	if (ret) {
		LOG_ERR("Invalid address %s", addr_str);
		return ret;
	}

	pool_base = addr;
	pool_base.s4_addr[3] += 1U; /* First lease after AP address (e.g. .1 -> pool from .2) */

	return net_dhcpv4_server_start(iface, &pool_base);
}

static int configure_dhcpv4_server_with_retry(struct net_if *iface, const char *addr_str)
{
	int ret;

	for (int attempt = 0; attempt < 10; attempt++) {
		ret = configure_dhcpv4_server(iface, addr_str);
		if (ret != -ENOENT) {
			return ret;
		}

		LOG_WRN("DHCPv4 start deferred (iface not ready), attempt %d/10", attempt + 1);
		k_sleep(K_MSEC(200));
	}

	return ret;
}

static bool wait_for_iface_up(struct net_if *iface, k_timeout_t timeout)
{
	int64_t end_ms = k_uptime_get() + k_ticks_to_ms_floor64(timeout.ticks);

	while (k_uptime_get() < end_ms) {
		if (net_if_is_admin_up(iface) && net_if_is_up(iface)) {
			return true;
		}

		k_sleep(K_MSEC(100));
	}

	return false;
}

static void log_iface_identity(const char *tag, struct net_if *iface)
{
	char if_name[16] = { 0 };
	char src_buf[NET_IPV4_ADDR_LEN];
	char mask_buf[NET_IPV4_ADDR_LEN];
	const struct net_in_addr *src = NULL;
	struct net_in_addr probe_addr;
	struct net_in_addr mask;
	int ret;

	if (iface == NULL) {
		LOG_ERR("%s: iface is NULL", tag);
		return;
	}

	ret = net_if_get_name(iface, if_name, sizeof(if_name));
	if (ret < 0) {
		LOG_WRN("%s: iface=%p idx=%d admin=%d up=%d name_err=%d",
			tag, iface, net_if_get_by_iface(iface),
			net_if_is_admin_up(iface), net_if_is_up(iface), ret);
		return;
	}

	(void)net_addr_pton(NET_AF_INET, "192.168.4.2", &probe_addr);
	src = net_if_ipv4_select_src_addr(iface, &probe_addr);
	mask = src ? net_if_ipv4_get_netmask_by_addr(iface, src) : (struct net_in_addr){ 0 };
	if (src) {
		(void)net_addr_ntop(NET_AF_INET, src, src_buf, sizeof(src_buf));
		(void)net_addr_ntop(NET_AF_INET, &mask, mask_buf, sizeof(mask_buf));
	}

	LOG_INF("%s: iface=%p idx=%d name=%s admin=%d up=%d src=%s mask=%s",
		tag, iface, net_if_get_by_iface(iface), if_name,
		net_if_is_admin_up(iface), net_if_is_up(iface),
		src ? src_buf : "none",
		src ? mask_buf : "none");
}

static int wifi_start_softap(void)
{
	struct net_if *iface = wifi_sap_iface();
	struct wifi_connect_req_params ap = {
		.ssid = (const uint8_t *)CONFIG_PICO_USBIP_AP_SSID,
		.ssid_length = sizeof(CONFIG_PICO_USBIP_AP_SSID) - 1U,
		.channel = WIFI_CHANNEL_ANY,
		.band = WIFI_FREQ_BAND_2_4_GHZ,
	};

	if (iface == NULL) {
		LOG_ERR("Wi-Fi SAP interface not available");
		return -ENODEV;
	}

	if (sizeof(CONFIG_PICO_USBIP_AP_PSK) == 1) {
		ap.security = WIFI_SECURITY_TYPE_NONE;
		ap.psk = NULL;
		ap.psk_length = 0U;
	} else {
		ap.security = WIFI_SECURITY_TYPE_PSK;
		ap.psk = (const uint8_t *)CONFIG_PICO_USBIP_AP_PSK;
		ap.psk_length = sizeof(CONFIG_PICO_USBIP_AP_PSK) - 1U;
	}

	LOG_INF("Starting SoftAP '%s' (channel any)", CONFIG_PICO_USBIP_AP_SSID);

	int ret = net_mgmt(NET_REQUEST_WIFI_AP_ENABLE, iface, &ap, sizeof(ap));
	if (ret == 0) {
		return 0;
	}

	ap.channel = 1U;
	LOG_WRN("SoftAP(any) failed: %d, retrying on channel 1", ret);
	return net_mgmt(NET_REQUEST_WIFI_AP_ENABLE, iface, &ap, sizeof(ap));
}

static void vbus_enable_at_boot(void)
{
#if DT_NODE_HAS_PROP(DT_PATH(zephyr_user), vbus_gpios)
	const struct gpio_dt_spec vbus = GPIO_DT_SPEC_GET(DT_PATH(zephyr_user), vbus_gpios);

	if (!gpio_is_ready_dt(&vbus)) {
		LOG_ERR("VBUS GPIO controller not ready");
		return;
	}

	if (gpio_pin_configure_dt(&vbus, GPIO_OUTPUT_ACTIVE) != 0) {
		LOG_ERR("VBUS GPIO configure failed");
		return;
	}

	LOG_INF("VBUS enable asserted on %s pin %u", vbus.port->name, vbus.pin);
#else
	LOG_WRN("No vbus-gpios in devicetree; enable VBUS in hardware or add zephyr_user,vbus-gpios");
#endif
}

static void wait_for_console_connection(void)
{
	const struct device *const console = DEVICE_DT_GET(DT_CHOSEN(zephyr_console));
	uint32_t dtr = 0U;
	int ret;

	if (!device_is_ready(console)) {
		LOG_ERR("Console device is not ready; continuing without DTR wait");
		return;
	}

	LOG_INF("Waiting for USB serial terminal (DTR) before Wi-Fi init");

	while (true) {
		ret = uart_line_ctrl_get(console, UART_LINE_CTRL_DTR, &dtr);
		if ((ret == 0) && (dtr != 0U)) {
			break;
		}

		if ((ret == -ENOTSUP) || (ret == -ENOSYS)) {
			LOG_WRN("Console does not support line control; skipping DTR wait");
			return;
		}

		k_sleep(K_MSEC(200));
	}

	LOG_INF("USB serial terminal connected");
}

#if DT_NODE_HAS_STATUS(DT_ALIAS(led0), okay)
static const struct gpio_dt_spec heartbeat_led = GPIO_DT_SPEC_GET(DT_ALIAS(led0), gpios);
static bool heartbeat_led_enabled;
static bool heartbeat_led_state;

static void heartbeat_led_init(void)
{
	if (!gpio_is_ready_dt(&heartbeat_led)) {
		LOG_WRN("LED device not ready; heartbeat disabled");
		return;
	}

	if (gpio_pin_configure_dt(&heartbeat_led, GPIO_OUTPUT_INACTIVE) != 0) {
		LOG_WRN("LED pin configure failed; heartbeat disabled");
		return;
	}

	heartbeat_led_enabled = true;
	heartbeat_led_state = false;
}

static void heartbeat_led_toggle(void)
{
	if (!heartbeat_led_enabled) {
		return;
	}

	(void)gpio_pin_set_dt(&heartbeat_led, heartbeat_led_state);
	heartbeat_led_state = !heartbeat_led_state;
}

#endif

int main(void)
{
	k_sleep(K_SECONDS(1));
#if DT_NODE_HAS_STATUS(DT_ALIAS(led0), okay)
	heartbeat_led_init();
#endif
	struct net_if *ap;
	int ret;
	wait_for_console_connection();
	vbus_enable_at_boot();

	ap = wifi_sap_iface();
	if (ap == NULL) {
		LOG_ERR("No SAP iface");
		while (true) {
#if DT_NODE_HAS_STATUS(DT_ALIAS(led0), okay)
			heartbeat_led_toggle();
#endif
			k_sleep(K_MSEC(120));
		}
	}
	log_iface_identity("SAP(before AP enable)", ap);

	struct net_in_addr ap_addr;
	struct net_in_addr netmask;

	ret = wifi_start_softap();
	if (ret) {
		LOG_ERR("SoftAP failed: %d", ret);
	} else {
		LOG_INF("SoftAP enable accepted");
	}
	ap = wifi_sap_iface();
	if (ap == NULL) {
		LOG_ERR("SAP iface unavailable after SoftAP enable");
	}
	log_iface_identity("SAP(after AP enable)", ap);

	net_addr_pton(NET_AF_INET, "192.168.4.1", &ap_addr);
	net_addr_pton(NET_AF_INET, "255.255.255.0", &netmask);

	(void)net_if_up(ap);
	if (!wait_for_iface_up(ap, K_SECONDS(3))) {
		LOG_WRN("AP iface not fully up yet (admin:%d link:%d)",
			net_if_is_admin_up(ap), net_if_is_up(ap));
	}
	log_iface_identity("SAP(before DHCP start)", ap);

	net_if_ipv4_set_gw(ap, &ap_addr);
	if (net_if_ipv4_addr_add(ap, &ap_addr, NET_ADDR_MANUAL, 0) == NULL) {
		LOG_ERR("Failed to set AP IPv4 address");
	}
	if (!net_if_ipv4_set_netmask_by_addr(ap, &ap_addr, &netmask)) {
		LOG_ERR("Failed to set AP netmask");
	}
	LOG_INF("AP IPv4 configured to 192.168.4.1/24");

	ret = configure_dhcpv4_server_with_retry(ap, "192.168.4.1");
	if (ret) {
		LOG_ERR("DHCPv4 server failed: %d", ret);
	}

	LOG_INF("USB/IP runs on port 3240; connect to Wi-Fi '%s' then use usbip on Linux",
		CONFIG_PICO_USBIP_AP_SSID);
	while (true) {
#if DT_NODE_HAS_STATUS(DT_ALIAS(led0), okay)
		heartbeat_led_toggle();
#endif
		k_sleep(K_MSEC(300));
	}
}

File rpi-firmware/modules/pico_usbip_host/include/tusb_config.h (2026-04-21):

#ifndef PICO_USBIP_TUSB_CONFIG_H
#define PICO_USBIP_TUSB_CONFIG_H

#ifdef __cplusplus
extern "C" {
#endif

#ifndef CFG_TUSB_MCU
#define CFG_TUSB_MCU OPT_MCU_RP2040
#endif

#ifndef CFG_TUSB_OS
#define CFG_TUSB_OS OPT_OS_NONE
#endif

#ifndef CFG_TUSB_RHPORT0_MODE
#define CFG_TUSB_RHPORT0_MODE OPT_MODE_HOST
#endif

#ifndef CFG_TUSB_MEM_SECTION
#define CFG_TUSB_MEM_SECTION
#endif

#ifndef CFG_TUSB_MEM_ALIGN
#define CFG_TUSB_MEM_ALIGN __attribute__((aligned(4)))
#endif

#define CFG_TUH_ENABLED 1
#define CFG_TUD_ENABLED 0

#define CFG_TUH_MAX_SPEED OPT_MODE_FULL_SPEED
#define CFG_TUH_ENUMERATION_BUFSIZE 256
#define CFG_TUH_DEVICE_MAX 4
#define CFG_TUH_HUB 1

/*
 * Keep class drivers disabled. Zephyr UHC consumer owns transfer orchestration.
 */
#define CFG_TUH_CDC 0
#define CFG_TUH_HID 0
#define CFG_TUH_MSC 0
#define CFG_TUH_VENDOR 0

#define CFG_TUH_API_EDPT_XFER 1

#ifndef CFG_TUSB_DEBUG
#define CFG_TUSB_DEBUG 0
#endif

#ifdef __cplusplus
}
#endif

#endif /* PICO_USBIP_TUSB_CONFIG_H */

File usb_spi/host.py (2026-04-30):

#!/usr/bin/env python3
import serial
import struct
import time

PORT = "/dev/ttyACM0"
BAUD = 115200  # literally useless but sereial port requires a buad rate to open


def frame_encode(payload: bytes) -> bytes:
    return struct.pack(">H", len(payload)) + payload


def parse_frames(buf: bytearray):
    frames = []
    while len(buf) >= 2:
        length = struct.unpack(">H", buf[:2])[0]
        if len(buf) < 2 + length:
            break
        payload = bytes(buf[2 : 2 + length])
        frames.append(payload)
        del buf[: 2 + length]
    return frames


def main():
    rx_buf = bytearray()

    with serial.Serial(PORT, BAUD, timeout=0.1) as ser:
        time.sleep(2)

        while True:
            payload = b"\xaa\xbb\xcc\xdd\xee"
            frame = frame_encode(payload)
            print(f"TX: {frame.hex()}")
            ser.write(frame)

            time.sleep(0.2)

            while ser.in_waiting:
                rx_buf.extend(ser.read(ser.in_waiting))

            for p in parse_frames(rx_buf):
                print(f"RX payload: {p.hex()}")

            time.sleep(1)


if __name__ == "__main__":
    main()

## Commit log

2026-04-02 Defaulit RP board
    [KiCAD_Custom_DRC_Rules_for_PCBWay.kicad_pcb, KiCAD_Custom_DRC_Rules_for_PCBWay.kicad_sch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]
2026-04-10 add nrf70
    [QFN48_6X6_NOR.stl, RP2350Adev.kicad_sch, SON_CX1612DB40000D0WLLCC_KAV.stl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]
2026-04-13 Added nRF5340
    [nRF5340.kicad_sch]
2026-04-13 add footprints
    [1725656.stp, 219-3M.STEP, 3382g-001-xxx.stp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]
2026-04-13 Muxful beginnings
    [RP2350Adev.kicad_sch, nRF7002.kicad_sch]
2026-04-13 Updated nRF5340 work
    [nRF5340.kicad_sch]
2026-04-13 Updated nRF5340 schematic
    [nRF5340.kicad_sch]
2026-04-14 link hierarchical sheet and switch from QSPI to SPI
    [RP2350Adev.kicad_sch, nRF5340.kicad_sch]
2026-04-14 Mucful Returns
    [USB_Mux_Periph.kicad_sch]
2026-04-14 add main
    [RP2350Adev.kicad_sch, USB_Mux_Periph.kicad_sch, main.kicad_sch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]
2026-04-15 Updated nRF5340 with footprints and labels
    [nRF5340.kicad_sch]
2026-04-15 Muxful Developings
    [RP2350Adev.kicad_sch, USB_Mux_Periph.kicad_sch]
2026-04-15 Muxful Schematics Done (Added external standalone 5V supply USB-C connector)
    [USB_Mux_Periph.kicad_sch]
2026-04-15 Muxful Assignings of Components and Foots
    [USB_Mux_Periph.kicad_sch]
2026-04-15 Added UART and final footprints
    [ABM11W-32.0000MHZ-8-D1X-T3.step, CM9V-T1A-32.768KHZ-9PF-20PPM-TA-QC.step, MLZ1608M100WTD25.step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]
2026-04-15 Combine subsheets
    [RP2350Adev.kicad_sch, USB_Mux_Periph.kicad_sch, main.kicad_sch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]
2026-04-17 Layout Assembly Attempt (Components not being transferred as expected, major issues)
    [RP2350Adev.kicad_sch, USB_Mux_Periph.kicad_pcb, USB_Mux_Periph.kicad_sch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]
2026-04-18 Combine subcircuits
    [RP2350Adev.kicad_sch, USB_Mux_Periph.kicad_sch, main.kicad_pcb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]
2026-04-18 Layout mostly complete, need to finalize layers
    [main.kicad_pcb]
2026-04-18 RF layout
    [main.kicad_pcb, nRF5340.kicad_sch, nRF7002.kicad_sch]
2026-04-18 Pushing Added Arts, Fixes to Overlapping Labels
    [main.kicad_pcb]
2026-04-18 fix footprint errors
    [RP2350Adev.kicad_sch, USB_Mux_Periph.kicad_sch, main.kicad_pcb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]
2026-04-19 Add silk
    [main.kicad_pcb]
2026-04-21 final fab files
    [BOM.xlsx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]
2026-04-21 add rpi pico firmware
2026-04-23 Adding interactive BOM, muxful death
2026-04-30 Debug Version of USB-SPI bridge for RP2350
